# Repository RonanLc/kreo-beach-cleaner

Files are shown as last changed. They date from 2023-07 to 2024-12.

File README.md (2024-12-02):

# Kreo Beach Cleaner - Robot Beach Cleaner 🌊

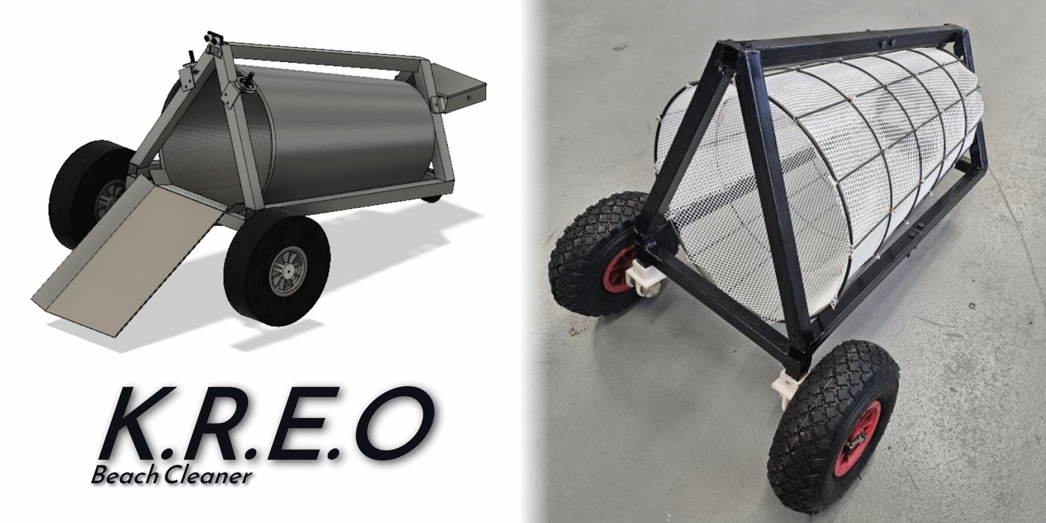
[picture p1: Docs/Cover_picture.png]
Cover picture


## 🌟 Project background

This project was carried out during an internship in Mauritius. The main objective was to design an autonomous robot capable of cleaning beaches while storing the collected waste. This project is part of an effort to preserve the environment and combat marine pollution.

## 🎯 Objectives
- **Beach cleaning** : Waste detection and collection.
- **Autonomy** : Navigation without human intervention.
- **Efficient storage**: Integration of a compartment for transporting collected waste.

## ⚙️ Main features

1. **Mechanical structure** :
   - Lightweight, robust chassis suitable for sandy terrain.
   - Collection system with ramp and sieve cylinder.
   - The 3D conception of the robot can be find [here](https://a360.co/3raTjkV).

2. **Electronic system** :
   - Arduino boards for sensor and motor control.
   - Sensors for obstacle detection and waste identification (ultrasound, cameras).

3. **Software and AI**:
   - Algorithms for autonomous navigation and obstacle avoidance.
   - Recognition system to distinguish waste from sand.

## 🛠️ Project structure

1. `Mechanical/` : 
   - 3D drawings and mechanical design documentation.
   - Details of collection system.

2. `Electronics/` :
   - Electronic schematics.
   - Motor and sensor configuration.

3. `Software:`
   - Code for Arduino and autonomous navigation algorithms.
   - Scripts for waste recognition.

## 🚀 Progress and next steps

- **Current**: Functional prototype in field-testing phase.
- **To come** :
  - Improved algorithms for greater detection accuracy.
  - Optimization of energy consumption.
  - Integration of additional sensors for environmental analysis.

## 📚 Documentation

- Documentation are available in the `Docs/` folder.
- The codes and IT structure are available in the `Code/` folder.

## 📫 Contact

For more information or to contribute to the project, contact me via [my GitHub](https://github.com/RonanLc).

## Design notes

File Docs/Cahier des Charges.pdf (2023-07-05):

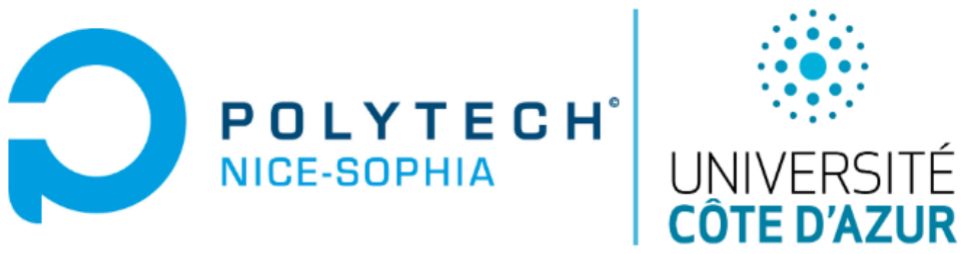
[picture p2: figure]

# Cahier des charges

Année 2023

# Robot nettoyeur de plage

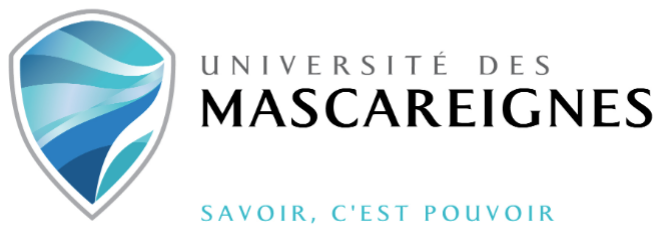
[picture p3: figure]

## Etudiant : BHIKIR Oumnia LE CORRONC Ronan LABAUVIE–RAFFAELLI Eva PORCEL Koralie

Université des Mascareignes, Avenue de la Concorde, Beau Bassin-Rose Hill, Maurice

I/ Contexte et Objectifs du projet

Maurice, une magnifique île située dans l’océan indien, est célèbre pour ses plages immaculées et ses eaux cristallines. Cependant, la préservation de cet environnement naturel présente un défi constant.
Les plages de Maurice attirent des milliers de visiteurs, bien que cela soit bénéfique pour l’industrie touristique, cela entraîne une augmentation des déchets et débris pouvant impacter la faune et la flore marine de l'île.
Pour lutter contre ce problème, dans le cadre d’un stage de six semaines au sein de l’université des Mascareignes. Koralie Porcel, Oumnia Bhikir, Eva Labauvie–Raffaelli et Ronan Le Corronc, étudiants ingénieurs venant de L'École polytechnique universitaire de l'université de Nice, proposons une approche novatrice : Un robot nettoyeur de plage.
Ce robot autonome sera donc conçu pour collecter les déchets ( bouteilles en plastique et canette soda … ) de manière efficace et respectueuse de l’environnement.
La solution technique ( figure 1 ) que nous proposons est un robot à roues muni d’un cylindre tournant à l’arrière, pour tamiser le sable. Le cylindre sera lié à une pente légèrement enfouie dans le sable, l’avancement du robot fera monter le sable à l'intérieur du cylindre en rotation, les déchets seront maintenus à l’intérieur et le sable passera par les mailles du cylindre.

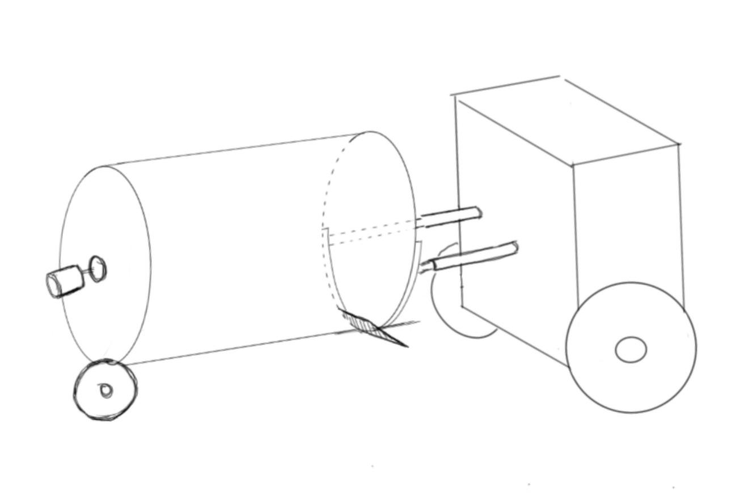
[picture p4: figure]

Figure 1 : Croquis du robot à roues liées à un cylindre à mailles

Toutefois, nous sommes conscients que la solution proposée ne permet pas de faire la différence entre corail, coquillage et déchet.
Pour ce faire, il faudra envisager une combinaison de méthodes et technologie, par exemple une vision par ordinateur basée sur l’IA capable de reconnaître la forme et caractéristique des coraux. Nous citons aussi la possibilité d’utilisation de capteurs de pression, les coquillages ont généralement une consistance plus dure que les déchets.
Finalement, une collaboration humaine sous forme d’un tri manuel est également envisageable.
En vue du temps accordé, notre objectif est la réalisation d’un robot fonctionnel capable de parcourir la plage et ramasser les déchets, le tri est une option à intégrer ultérieurement.

II/ Cahier des charges

Le robot devra être adapté aux reliefs créés par le sable présent sur la plage, il sera donc conçu pour se déplacer sur un terrain irrégulier.
Il sera équipé d'un dispositif permettant de ratisser le sable et de le tamiser afin de n'en collecter que les déchets.
Par ailleurs, le robot sera muni d'un capteur de distance pour détecter les éventuels obstacles pouvant se trouver sur son chemin.
Il sera autonome dans une zone prédéfinie afin d'éviter de s'orienter directement vers l'océan.
Nous explorerons plus en détail à présent les étapes de mise en place du projet et ses caractéristiques, pour découvrir comment la combinaison de la technologie et de la préservation de l'environnement peut ouvrir la voie vers un avenir plus propre et plus durable pour les plages de Maurice et au-delà.

➔ Conception

1. Châssis : Le châssis va permettre au robot de pouvoir se mouvoir dans le sable
2. Dispositif de collecte : Le dispositif de collecte permet de ratisser le sable et les déchets, les tamiser et stocker les déchets à l'intérieur du robot.
3. Déplacement et détection d’obstacle : Le robot va pouvoir se déplacer en autonomie dans une zone prédéfinie. Il pourra également détecter les obstacles sur son chemin.
4. Energie : L’énergie est un élément essentiel du robot pour pouvoir le faire fonctionner.

➔ Réalisation

1. Châssis
2. Dispositif de collecte
3. Déplacement et détection d’obstacle
4. Energie

III/ Méthodologie employée

➔ Conception

Etape 1 :

- Châssis
Le châssis est la base du robot. Il se doit rigide et assez solide pour pouvoir supporter le poids et les contraintes appliqués sur le robot. Il devra également être assez léger pour ne pas surcharger les moteurs servant au déplacement. Et il devra résister au sel et à l’humidité fortement présents sur une plage.

Il sera donc composé en trois majeures parties :

- La première, située à l’arrière, servant à soutenir le cylindre de collecte, il devra le tenir fermement tout en le permettant de tourner sur lui-même.
- Une deuxième, située à l’avant du robot, servant à tenir et protéger toute l'électronique du robot, ses cartes de commandes, capteur et alimentation.
- Une troisième, faisant la taille du robot pour pouvoir assembler les deux parties précédentes et rendre rigide l'ensemble.

Etape 2 :

- Dispositif de collecte
Nous allons utiliser un cylindre non uniforme métallique de 25 cm de diamètre en bas et 37 cm de diamètre en haut par 57 cm de hauteur avec une maille fine.
Le cylindre possède à l’avant une ouverture et une petite pente qui permettra de laisser le sable et les déchets rentrer dedans lors du déplacement du robot.
Le cylindre est penché. En effet la distance entre le sol et l'entrée des déchets sera plus haute que celle avec le bout du cylindre.
A l’arrière du cylindre, il y aura une roue assurant la fluidité du déplacement, de sorte à éviter les frottements avec le sol et ralentir le mouvement.
Le diamètre d’un sable fait entre 60 microns à 2mm. Pour pouvoir le tamiser, nous allons rajouter un grillage métallique qui laissera passer le sable mais gardera les déchets. Pour cela, le cylindre métallique va tourner en permanence.
Les déchets vont rester stockés dans le cylindre avec le sable directement remis au sol. Une fois le cylindre rempli, il arrêtera de tourner.
Nous le précisons ici également, notre solution technique ne tient pas en compte le tri et la distinction entre corail et déchet.

Etape 3 :

- Déplacement et détection d’obstacle Les utilisateurs du robot vont définir une zone de travail rectangulaire de nettoyage et préciser où le robot sera placé (dans un des coins du rectangle).
Une fois la zone précisée, le mouvement se fera de façon serpentine, sinueuse et ondulatoire. Le robot va avancer tout au long de la zone, il tournera à 180° puis reviendra sur ses pas suivant la longueur qui suit, jusqu’à ce que toute la zone soit ratissée.
Si un être vivant se présente dans la zone, le robot attendra qu’il parte.

Etape 4 :

- Energie
Les moteurs doivent être alimentés en 12V. La carte de contrôle peut recevoir une tension d’alimentation entre 7V et 12V. Elle va convertir cette énergie en 5V pour alimenter les autres composants électroniques (tels que les capteurs de distance).
Nous allons donc utiliser une source d’alimentation à 12V pour pouvoir alimenter le robot en entier qui sera branché en parallèle aux moteurs et à la carte de contrôle.

Phase 2 Réalisation

Etape 1 :

- Châssis
Nous avons donc choisi de réaliser le châssis en acier. Il sera fait à partir de tube rectangulaire et de plaque d'aluminium. Cela nous permettra d’allier légèreté et solidité pour un coût raisonnable.
Les tubes et les plaques seront maintenus ensemble à l’aide de soudure et de différents types de visserie.
Le métal étant sensible à l’oxydation accélérée par l’eau et le sel, il devra être protégé par des revêtements anti-rouille et de la peinture.
Pour pouvoir fixer les différentes pièces et composants électroniques, nous utiliserons une imprimante 3D pour réaliser des pièces sur mesure en plastique. Dans le cas où nous n'y avons pas accès, nous utiliserons de nouveau du métal pour réaliser des supports sur mesure.

Etape 2 :

- Dispositif de collecte
Nous allons utiliser un panier à linge comme cylindre métallique.
Le diamètre d’un sable fait entre 60 microns à 2mm. Le grillage métallique que nous implémenterons aura des trous de 3mm d’épaisseur pour ne laisser passer que le sable. Une roue basse pression non motorisée sera utilisée à l'arrière.
Pour pouvoir faire tourner le cylindre continuellement, nous allons utiliser un moteur CC.
De plus, pour pouvoir vérifier si le cylindre est trop rempli, nous utiliserons un capteur de distance à ultrason de telle façon à voir la quantité de déchets contenus.

Etape 3

- Déplacement et détection d’obstacle Pour pouvoir préciser la zone de nettoyage, nous allons utiliser une application que nous mettrons en place sur téléphone. Les informations fournies par l’utilisateur seront mises sur l'application et seront transmises au robot à l’aide d’un module bluetooth qui assurera la communication entre le téléphone et le robot. Nous envisageons d'utiliser Bluetooth electronics comme application.

Etape 4

- Energie
Pour pouvoir alimenter le robot, 2 options s'offrent à nous : -une batterie au plomb
-un panneaux solaire + batterie pour stocker l'énergie.
Il faudra de plus pouvoir recharger le robot sur secteur.

IV/ Planning (Gantt)

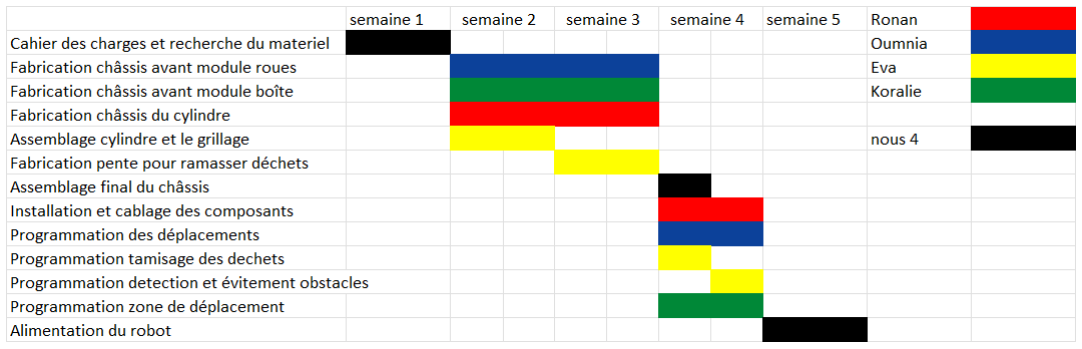
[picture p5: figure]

V/ Tableau des composants

Noms des composants | Ref/images
Carte arduino méga | https://transcom-electronics.com/product/arduino-atmega-2560-avr-usb-board/ (https://transcom-electronics.com/product/arduino-atmega-2560-avr-usb-board/)
3 roues basse pression | https://www.vevor.fr/roues-de-plage-c_11478/vevor-roues-de-ballo n-de-plage-nbsp-pneus-ballon-roues-de-plage-26-cm-capacite-35 -kg-p_010262194457 (https://www.vevor.fr/roues-de-plage-c_11478/vevor-roues-de-ballon-de-plage-nbsp-pneus-ballon-roues-de-plage-26-cm-capacite-35-kg-p_010262194457)
3 Moteur DC 12V 25GA 10RPM | https://transcom-electronics.com/product/25ga-12v-10rpm/
2 * Motor driver - Double pont en H | https://transcom-electronics.com/product/l298-dc-stepper-motor-driver-dual-h-bridge/ (https://transcom-electronics.com/product/l298-dc-stepper-motor-driver-dual-h-bridge/)
2 capteur de distance ultrason | https://transcom-electronics.com/product/ultrasonic-distance-measuring-transducer/ (https://transcom-electronics.com/product/ultrasonic-distance-measuring-transducer/)
1 module bluetooth | https://transcom-electronics.com/product/wireless-bluetooth-rf-serial-module-4-pin/ (https://transcom-electronics.com/product/wireless-bluetooth-rf-serial-module-4-pin/)

Batterie

Roulement à bille

Tube rectangulaire en acier

Plaque d’aluminium

VI/ Schéma cinématique

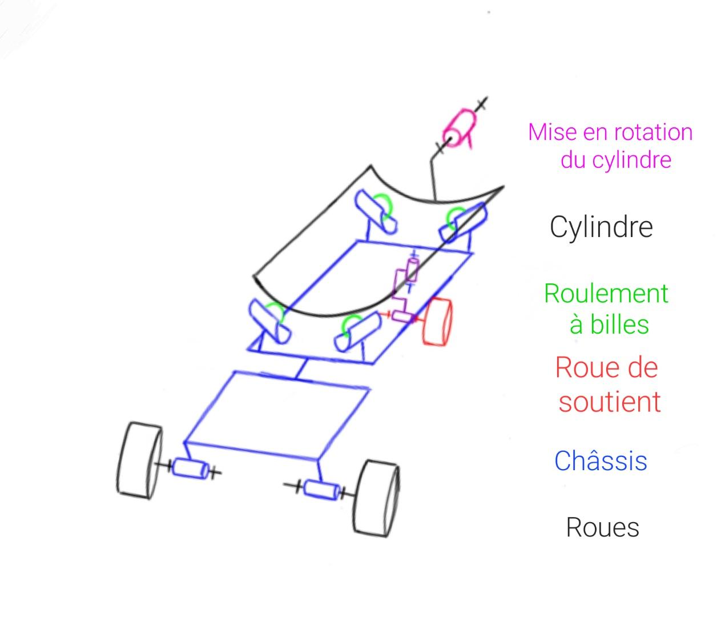
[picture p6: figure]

Figure 2 : schéma cinématique

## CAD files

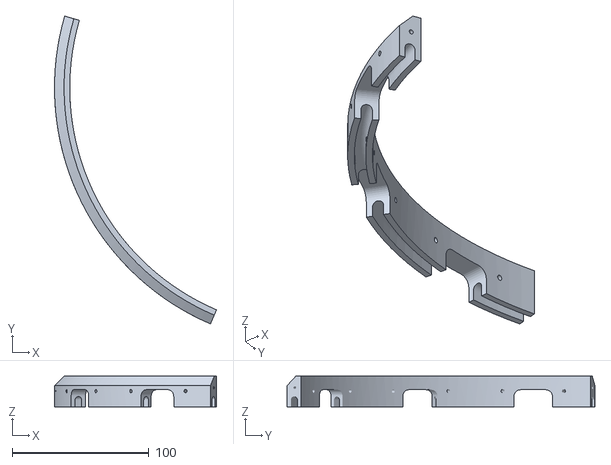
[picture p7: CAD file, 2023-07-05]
Parts/Cylindre/Contour STL/Contour_part3.stl
118.6 x 225.3 x 22.6

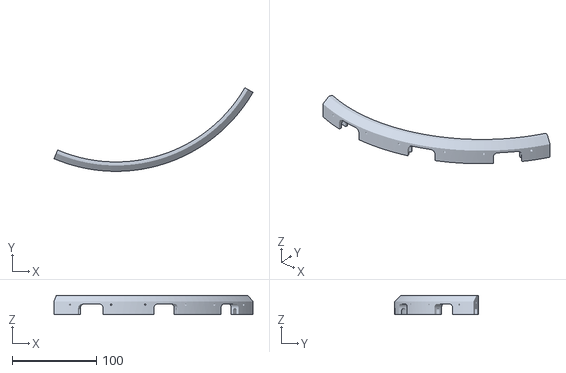
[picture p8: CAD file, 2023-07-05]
Parts/Cylindre/Contour STL/Contour_part4.stl
236.6 x 99.5 x 22.6

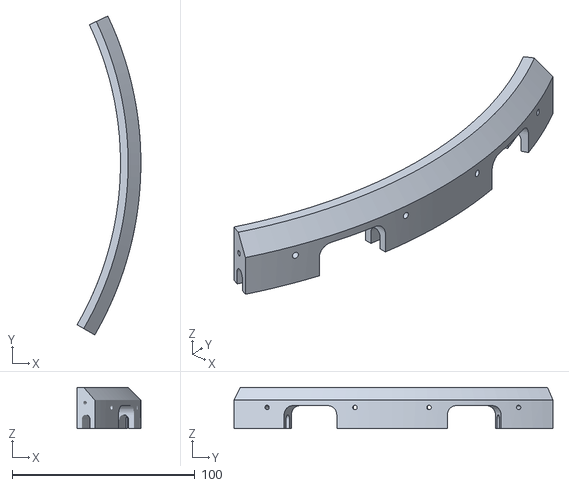
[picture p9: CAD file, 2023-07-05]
Parts/Cylindre/Contour STL/Contour_part2.stl
34.9 x 174.6 x 22.6

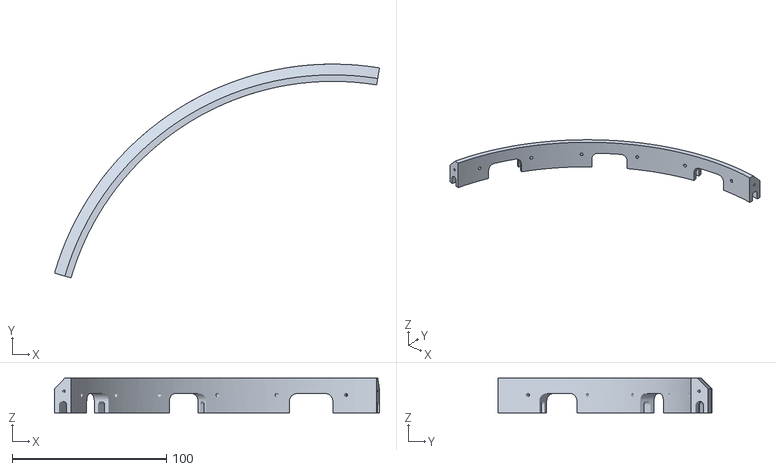
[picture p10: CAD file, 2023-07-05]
Parts/Cylindre/Contour STL/Contour_part1.stl
210.8 x 138.7 x 22.6

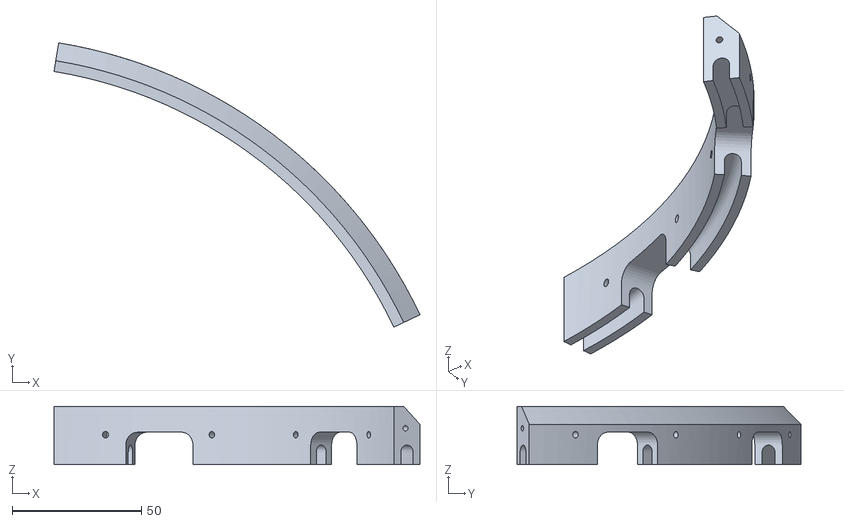
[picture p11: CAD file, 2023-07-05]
Parts/Cylindre/Contour STL/Contour_part5.stl
141.4 x 109.9 x 22.6

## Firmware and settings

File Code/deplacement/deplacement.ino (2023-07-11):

#include <math.h>

//### parameters bluetooth sensor ###
bool goodWidth=false, goodLength=false;
bool again=false;
int value;
int val; //informations if the user set the width or the length
float rank=0.1;

//### parameters ultrasonic sensor ###
#define trigPin 7  //pin 7
#define echoPin 8  //pin 8

float USrange();
int minRange = 30;  //en centimetres

float distance;  //en centimetres
float parcours[2];
int orientation = 1;

float largRobot = 0.29; 
float largRoue = 0.06;

float turnSpeed = 3; // in seconds

int length, width; // longueur, largueur in meters

#define memorySize 10
float distMemory[memorySize];

//### parameters for motor driver ###
#define enA 2  //pin 2
#define motorL 0
#define motorR 2

#define forward 0
#define backward 1

float defaultSpeed = 2;  //speed of the robot in meters per second

int Hbridge[4] = { 5, 6, 10, 9 };  //in1 -> pin5, in2 -> pin6, in3 -> pin10, in4 -> pin9

void motorControl(int motor, int rotation, float mps);  //motor is for right and left motor
                                                     //rotation is for the direction, 0 -> forward, 1 -> backward
                                                     //mps is for the speed of the rotation, it's in meters per second

int robotState = 3;   // 0 : démarrage d'un cycle nettoyage
                      // 1 : Robot en fonctionnement
                      // 2 : Robot en pause (obstacle devant)
                      // 3 : Nettoyage terminé
                      // 4 : Robot en pause (application)

long timer[4];
long timeSave;

void setup() {
  Serial.begin(9600);

  //### setup bluetooth sensor ###
  Serial1.begin(9600);
  Serial1.print("*1"+String("")+"*");
  Serial1.print("*2"+String("")+"*");

  //### setup ultrasonic sensor ###
  pinMode(trigPin, OUTPUT);  // Sets the trigPin as an Output
  pinMode(echoPin, INPUT);   // Sets the echoPin as an Input

  //### setup driver motor ###
  pinMode(enA, OUTPUT);
  for (int i = 0; i < 4; i++) {
    pinMode(Hbridge[i], OUTPUT);
  }

  Serial.println(USrange());

  Serial.println("Setup done.");

  delay(500);
}



void loop() {

  if(robotState == 3){ // Nettoyage terminé

    reset(); // reset l'intégralité des variables
    
    for (int i = 0; i < memorySize; i++) {
      distMemory[i] = USrange();
      delay(1);
    }

    // ***** attendre les infos bluetooth et setup everything *****
    while (robotState==3){
    setSetup();          //configure la longueur et la largeur 
    checkStartCycle();   // change le statue du robot si le cycle de nettoyage peut commencer
    }
  }

  // si recois stop du bluetooth, mettre le nettoyage en pause
  changeRobotState();

  if(robotState != 3 && robotState != 4){

    distance = mesure();

    checkWay(distance);

    timeSave = timing(robotState);

    //parcours[0] = (float(length)/2 + (float(length)/2)*-orientation) + (timeSave * defaultSpeed/1000)*orientation;
    //parcours[0] = (timeSave * defaultSpeed/1000)*orientation;
    parcours[0] = timeSave * defaultSpeed/1000;

    Serial.println(timeSave);
    Serial.print("X : ");
    Serial.print((float(length)/2 + (float(length)/2)*-orientation) + parcours[0]*orientation);
    Serial.print(" m. / Y : ");
    Serial.print(parcours[1]);
    Serial.println(" m.");

    if(parcours[0] > length){
      turn(orientation);
      orientation = orientation*(-1);
    }

  }

  delay(10);
}


// ### FONCTION POUR MOTORISATION ###

void motorControl(int motor, int rotation, float mps) {
  digitalWrite(Hbridge[motor], rotation % 2);
  digitalWrite(Hbridge[motor + 1], (rotation + 1) % 2);

  int speed = (mps / ((150 / 60) * (260 * M_PI) / 1000)) * 255;
  analogWrite(enA, speed);
}

void checkWay(float distance){  
  if (distance > minRange) {
    if (robotState != 1){
      timer[0] = millis();
      robotState = 1;
      motorControl(motorL, forward, defaultSpeed);
      motorControl(motorR, forward, defaultSpeed);
      Serial.println("Move");
    }
  } else {
    if (robotState != 2){
      robotState = 2;
      motorControl(motorL, forward, 0);
      motorControl(motorR, forward, 0);
      Serial.println("Stop");
    }
  }
}

long timing(int robotState){
  if(robotState == 1){
      timer[1] = millis()-timer[0]; 
      timer[3] = timer[2] + timer[1];
  }
  else if(robotState == 2){
    timer[2] = timer[3];
  }
  return timer[3];
}

void turn(int orientation){ 

  float turnSpect[4]; // 0 : distance roue interieur ; 1 : distance roue exterieure ; 2 : vitesse roue interieur ; 3 : vitesse roue exterieur
  turnSpect[0] = M_PI * ((largRoue/2) + 0.25 - (largRobot/2));
  turnSpect[1] = M_PI * ((largRoue/2) + 0.25 + (largRobot/2));
  
  turnSpect[2] = ((turnSpect[0] / turnSpeed) / ((150 / 60) * (260 * M_PI) / 1000)) * 255;
  turnSpect[3] = ((turnSpect[1] / turnSpeed) / ((150 / 60) * (260 * M_PI) / 1000)) * 255;

  if(orientation > 0){
    motorControl(motorR, backward, turnSpect[2]);
    motorControl(motorL, forward, turnSpect[3]);
    Serial.println("Right turn end correcly");
  }
  
  else if(orientation < 0){
    motorControl(motorL, backward, turnSpect[2]);
    motorControl(motorR, forward, turnSpect[3]);
    Serial.println("Left turn end correcly");
  }

  delay(1000*turnSpeed);

  checkWay(0);

  delay(500);

  parcours[1] += largRobot; // largeur de la rampe

  if(parcours[1] - largRobot >= width){
    robotState = 3;
    Serial.println("Nettoyage terminé !");  
  }

  for(int i = 0; i < 4; i++){  // Sert à reset les timer de déplacement
    timer[i] = 0;              //
  }                            //
  timer[0] = millis();         //
}
// ### FONCTION POUR CATPEUR BLUETOOTH ###
bool checkZone(){   // verrifie si la valeur est bien un chiffre
  if  (value<0 || value>9){
    Serial.println("not good");
    Serial.println(val);
    Serial1.print("*"+String(val)+String("Incorrect values")+"*");
    return false;
  }
  return true;
}
void good(){
  Serial1.print("*"+String(val)+String("Good")+"*");
  if (val==1){goodWidth=true;}
  else{goodLength=true;}
}
void setValue(){
  if(val==1){width=width*rank+value;}
  else {length=length*rank+value;}
}
void setSetup(){
  if (Serial1.available()){  //si on capte le bluetooth : 
    value=Serial1.read()-48; //on lit la valeur que l'application envoie
    if(value==60){          //si c'est cette valeur, ca correspond à la largeur
      again=true;
      goodWidth=false;      // la largeur n'est plus bonne
      Serial.println("It is a width");
      val=1;
      rank=0.1;
      width=0;
    }
    else if (value==28){     //si c'est cette valeur, ca correspond à la longueur
      again=true;
      goodLength=false;      //la longueur n'est plus bonne
      Serial.println("It is a length");
      val=2;
      rank=0.1;
      length=0;
    } 
    else if (value==22){     //si c'est la fin de la reception 
      Serial.print("The width is : ");
      Serial.println(width);
      Serial.print("The length is : ");
      Serial.println(length);
    }
    else if (!checkZone()){// si la valeur n'est pas un chiffre correcte
      again=false;
    }
    else if (again){   // on regarde les chiffres envoyés
      rank*=10;
      setValue();
      good();
    }
  }
}
//Verrifie que tout soit bon pour commencer un cycle de nettoyage
void checkStartCycle(){
  if (Serial1.available()){
    val=Serial1.read();
    if(goodLength && goodWidth && val=="m"){ 
      robotState=0;
    }
  }
}
//Si la longueur et la largeur sont bonne regarde dans quel état est le robot (arret ou marche)
void changeRobotState(){
  if(goodLength && goodWidth){   
    if (Serial1.available()){
      val=Serial1.read();
      if (val=="m"){robotState=1;}
      else if (val=="p"){robotState=2;}
    }
  }
}


// ### FONCTION POUR CAPTEUR ULTRA-SON ###

float USrange() {
  long duration;
  float distance;
  // Clears the trigPin
  digitalWrite(trigPin, LOW);
  delayMicroseconds(2);
  // Sets the trigPin on HIGH state for 10 micro seconds
  digitalWrite(trigPin, HIGH);
  delayMicroseconds(10);
  digitalWrite(trigPin, LOW);
  // Reads the echoPin, returns the sound wave travel time in microseconds
  duration = pulseIn(echoPin, HIGH);
  // Calculating the distance
  distance = duration * 0.034 / 2;
  // Prints the distance on the Serial Monitor
  return distance;
}

void sort(float arr[]) {
  for (int i = 0; i < memorySize - 1; i++) {
    for (int j = 0; j < memorySize - i - 1; j++) {
      if (arr[j] > arr[j + 1]) {
        int temp = arr[j];
        arr[j] = arr[j + 1];
        arr[j + 1] = temp;
      }
    }
  }
}

float mesure(){
  float distSort[memorySize];

  for(int i=0; i<memorySize-1; i++){
    distMemory[i] = distMemory[i+1];
  }

  distMemory[memorySize-1] = USrange();

  for (int i = 0; i < memorySize; i++) {
    distSort[i] = distMemory[i];
  }

  sort(distSort);

  return distSort[int(memorySize / 2)];
}

void reset(){

  timeSave = 0;

  for(int i = 0; i < 4; i++){  // Sert à reset les timer de déplacement
    timer[i] = 0;              //
  }       

  for(int i = 0; i < 2; i++){  // Sert à reset les distances parcourus
    parcours[i] = 0;           //
  }  

  distance = 0;
  orientation = 1;

  for (int i = 0; i < memorySize; i++) {
    distMemory[i] = 0;
  }

  length = 0;
  width = 0;
}
